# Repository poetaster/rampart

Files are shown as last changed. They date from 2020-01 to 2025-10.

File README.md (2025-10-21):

# rampart
An arduino semi-modular synth companion to keep, moat and bastl's kastle.

Rampart can use an Arduino Nano or an LGT8F238. I sell them with the latter chip since it's twice as fast and has on more 16 bit timer:

 The Mozzi library is used for some synthesis sketches and some are just direct PWM with timers.

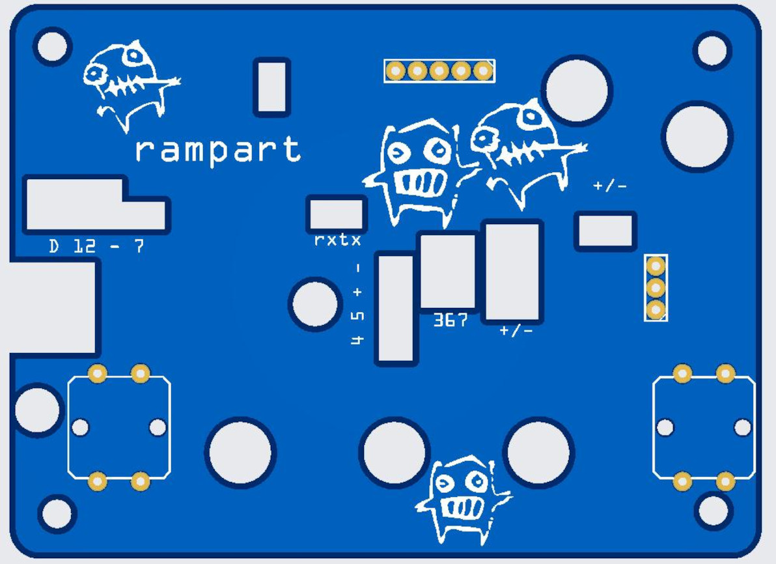
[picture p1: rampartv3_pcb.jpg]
V3 top pcb


## Hardware

* 3 pots
* 1 encoder w/button
* 2 buttons
* tactile switch w/LED
* CV inputs (analog)
* header for a SSD1306 display 
* analog filter/volume control
* audio/clock in
* audio wired stereo out
* headers for most digital and analog pins

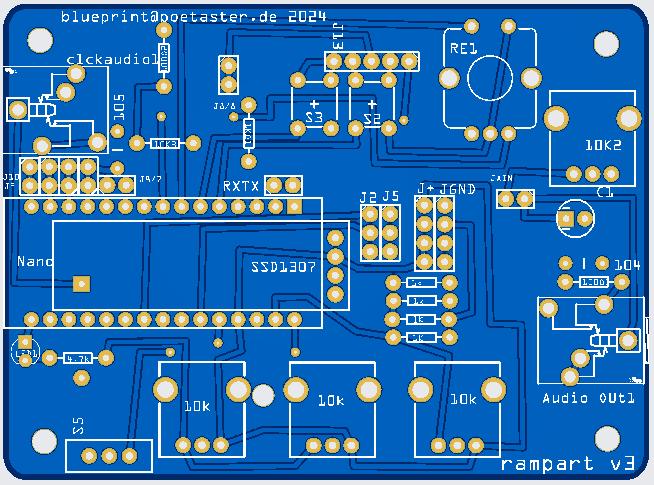
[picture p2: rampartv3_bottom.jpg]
V3 bottom pcb


Analog Pins 0-2 are potentionmeters. Analog pins 3-7 (4 avaible as an input) are used for modulation signal inputs. 

Pins 4&5, also SCL/SDA are layed out such that a SSD1306 could be used for a display.

Digital Pin 9 is audio (PWM) out, the Mozzi standard. 

Digital 2 - 6 are used for two buttons, an encoder and encoder button.

The layout includes an analog lowpass/volume knob and analog clock/audio in (pocket operator compatible).

The two buttons are located on the top pcb as is a 3pin header which is layed out GND/IO/VCC for connecting things like touch panels.

## Fritzing 

There are two Fritzing files used, one for the main pcb and one for the top (pictured above).

## Physical inputs

A note on -/+ located to the left below the volume knob ... these can also be used as input ;) If you take an internal signal (say my moat or a korg micromodular) you can use the filter to simply 'mix' the signals.

## Arduino Sketches

Of the sketches in the Firmware directory, those I use often and are well tested:
1. rampart3-bytebeats
2. DUAL_LFO
3. Modulove alternate function generator (burst, generative sequence, polyrythm, adsr, multimode env).
4. shepard-FM-chord 3 synths in one.

These can be flashed using the webflasher at https://poetater.org/webflasher 

To edit the sketches you can use the arduino ide. 
* install the ide from https://www.arduino.cc/en/software (I still use the 1.8.19 version)
* install the board support https://github.com/dbuezas/lgt8fx#how-to-install
* install the support library EncoderButton from Philip Fletcher (-> Tools -> Manage Libraries)
* download the lates source code from https://github.com/poetaster/rampart/releases (or do a git clone if you use git)
* open up a sketch in the firmware directory ( for instance rampart3-bytebeat)

The currently most complete sketch is the rampart3-bytebeat sketch. 

A number of Arduino sketches being updated include 2 synths (switch with button 3 on digital pin 2) which have 3 to 4 variable parts of the signal. Both sketches share the wavepacket object as 1st synth. One has PDResonant as second, one an FM synth as second synth.

So, Patch 1 is always a wavelet (based on the wavelet example with mozzi) synth and Patch 2 is an FM synth or PDResonant. Also still rough ideas.

This synth works well with Keep (moat), my analog synth and also with Bastl's Kastle synth. I've also played it with Korg's micro modular which works quiet well (in both directions).

I've included a granular synth without mozzi as an example and two versions of a 'glitch synth' from other sources modified to work with rampart.

## Upgrading firmware with hex files

First ensure you have drivers installed if you're on windows or mac. On linux you should not need to install a driver. A good reference for the usb drivers (which work form most arduino boards or the lgt in rampart):
https://learn.sparkfun.com/tutorials/how-to-install-ch340-drivers/all

The most current firmware hex files will be included in this directory and can be flashed  as follows

### linux: the device will most probably be ttyUSB0 as below:

* install avrdude using package manager 
* attach the rampart  to usb
* execute: avrdude -c arduino -b 57600 -F -P /dev/ttyUSB0 -p atmega328p -U flash:w:rampart3-bytebeats.ino.hex

### windows:

* having installed the driver, above
* install avrdude from https://github.com/avrdudes/avrdude/releases (windows x64, x86 or arm64)
* attach the rampart  to usb
* execute command: wmic path Win32_SerialPort Where "Caption LIKE '%%COM%%'" Get Description, DeviceID
* note the DeviceID of the "USB Serial Device" which will  be something like: "COM5" 
* using the DeviceID you've noted, adapt the following command (here -PCOM5).
* in the directory where you placed the hex file execute: avrdude.exe -patmega328p -carduino -D -PCOM5 -b57600 -Uflash:w:rampart3-bytebeats.ino.hex

### macintosh:

* install the usb driver for the rampart using instructions from : https://github.com/WCHSoftGroup/ch34xser_macos has a .pkg file you can install.
* install avrdude through MacPorts or Homebrew. (with home-brew it: brew install avrdude).
* attach the rampart  to usb
* in a terminal execute: "ls /dev/tty*" and note names with tty.wch in them  like : tty.wchusbserial1234
* from the directory where you downloaded the hex file execute: avrdude -c arduino -b 57600 -F -P /dev/tty.wchusbserial1234 -p atmega328p -U flash:w:rampart3-bytebeats.ino.hex

## Sales :)

I sell the latest versions of these as kits and completeed build at https://poetaster.org, on https://tonetoys.etsy.com and on Tindie:


# Historical versions

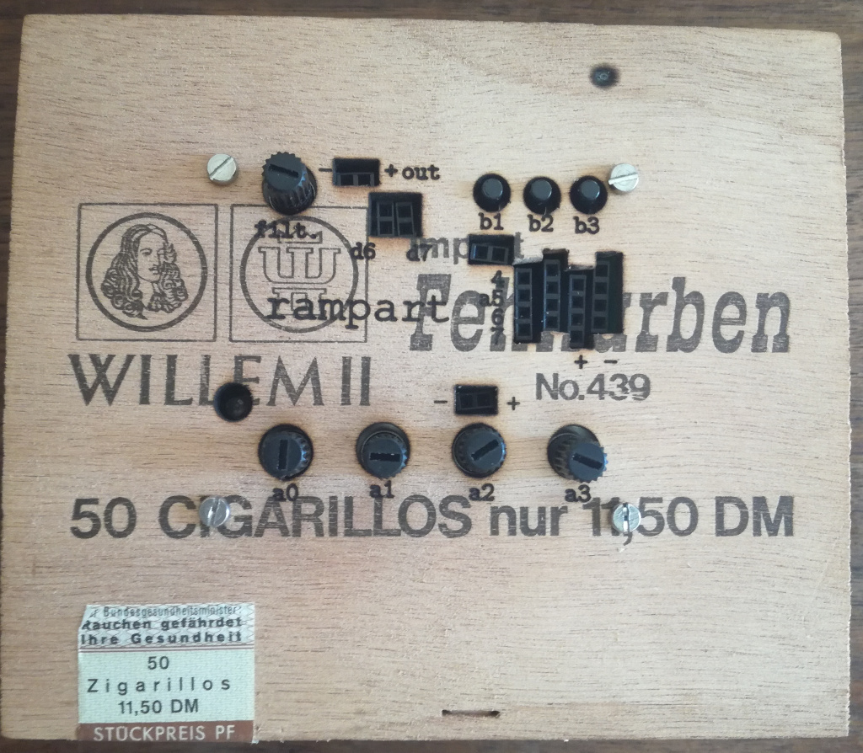
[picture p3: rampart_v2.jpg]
laser cut and etched prototype, v2


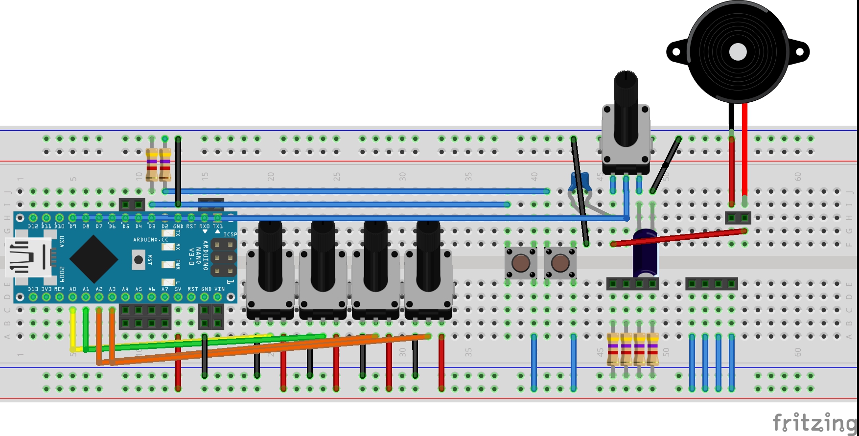
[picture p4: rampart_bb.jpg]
BreadBoard view


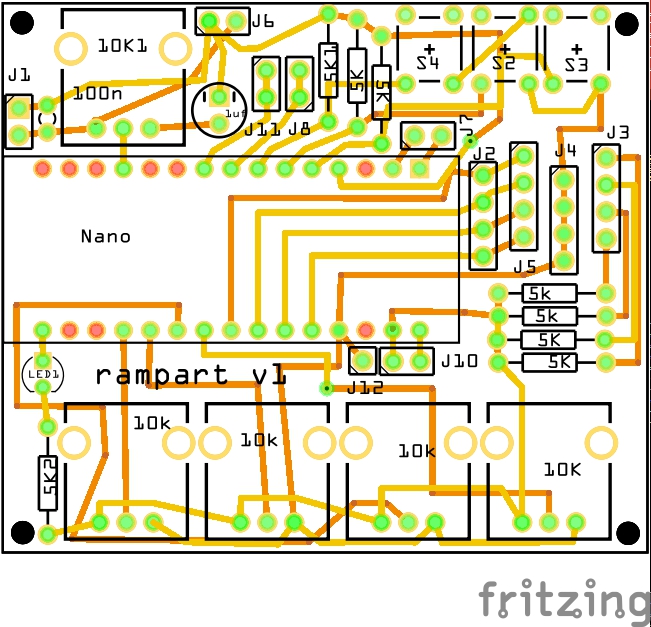
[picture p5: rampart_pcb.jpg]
PCB view


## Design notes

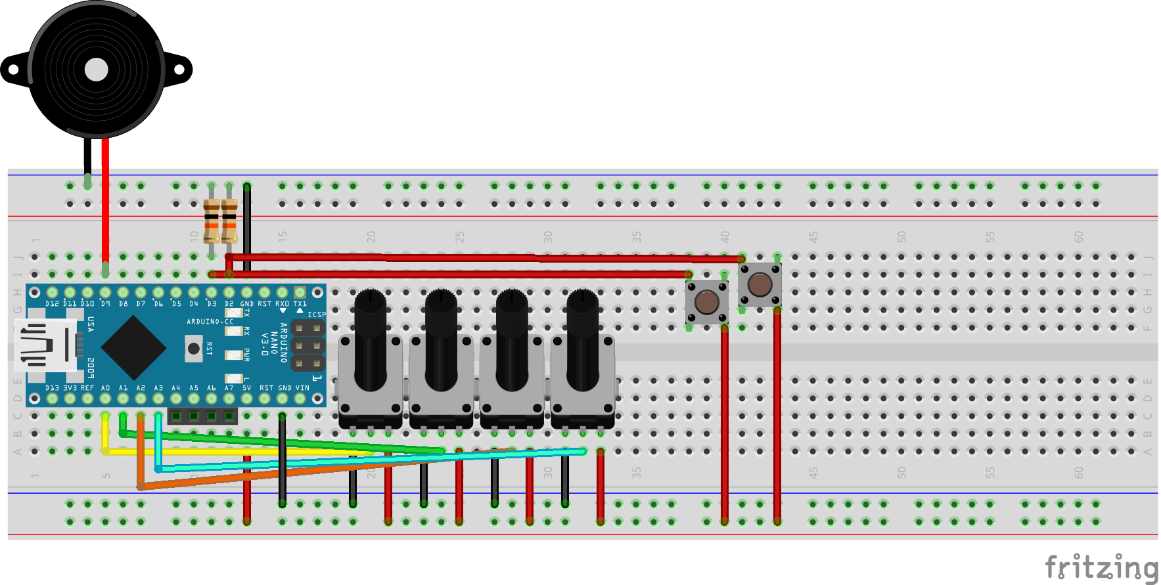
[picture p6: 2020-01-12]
rampart_bb.png

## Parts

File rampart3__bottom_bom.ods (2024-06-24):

Label | Part Type | mn | mpn | part number | cost | price
100Ω1 | 100Ω Resistor |  |  |  | 0.01 | 0.015
100Ω2 | 100Ω Resistor |  |  |  | 0.01 | 0.015
104 | Capacitor |  |  |  | 0.03 | 0.045
105 | Capacitor |  |  |  | 0.03 | 0.045
10k | Rotary Potentiometer (Small) |  |  |  | 0.17 | 0.255
10k | Rotary Potentiometer (Small) |  |  |  | 0.17 | 0.255
10k | Rotary Potentiometer (Small) |  |  |  | 0.17 | 0.255
10K2 | Rotary Potentiometer (Small) |  |  |  | 0.17 | 0.255
10K3 | 10kΩ Resistor |  |  |  | 0.01 | 0.015
1K | 1kΩ Resistor |  |  |  | 0.01 | 0.015
1K | 4.7kΩ Resistor |  |  |  | 0.01 | 0.015
1k | 1kΩ Resistor |  |  |  | 0.01 | 0.015
1k | 1kΩ Resistor |  |  |  | 0.01 | 0.015
1KΩ1 | 1kΩ Resistor |  |  |  | 0.01 | 0.015
4.7k | 4.7kΩ Resistor |  |  |  | 0.01 | 0.015
Audio OUt1 | Audio Jack (TRS) 3.5mm |  |  |  | 0.25 | 0.375
clckaudio1 | Audio Jack (TRS) 3.5mm |  |  |  | 0.25 | 0.375
J+ | Generic female header - 4 pins |  |  |  | 0.06 | 0.09
J2 | Generic female header - 3 pins |  |  |  | 0.05 | 0.075
J5 | Generic female header - 3 pins |  |  |  | 0.05 | 0.075
J9 | Generic female header - 2 pins |  |  |  | 0.04 | 0.06
J10 | Generic female header - 2 pins |  |  |  | 0.04 | 0.06
J11 | Generic female header - 2 pins |  |  |  | 0.04 | 0.06
J12 | Generic female header - 2 pins |  |  |  | 0.04 | 0.06
J13 | Generic female header - 5 pins |  |  |  | 0.06 | 0.09
J8/7 | Generic female header - 2 pins |  |  |  | 0.04 | 0.06
J8/8 | Generic female header - 2 pins |  |  |  | 0.04 | 0.06
JAIN | Generic female header - 2 pins |  |  |  | 0.04 | 0.06
JGND | Generic female header - 4 pins |  |  |  | 0.06 | 0.09
LED1 | Red (633nm) LED |  |  |  | 0.01 | 0.015
Nano | Arduino Nano (Rev3.0) |  |  |  | 1.9 | 2.85
RE1 | Rotary Encoder |  |  |  | 0.7 | 1.05
RXTX | Generic female header - 2 pins |  |  |  | 0.04 | 0.06
S2 | Pushbutton |  |  |  | 0.06 | 0.09
S3 | Pushbutton |  |  |  | 0.06 | 0.09
S5 | SPST Switch |  |  |  | 0.04 | 0.06
SSD1307 | OLED Mono 0.56 inch blue or white |  |  |  | 2.35 | 3.525 | 2.50 long | 4.04 large
VCC1 | 4 x AAA Battery Mount |  |  |  | 0.89 | 1.335
Jarduino | Generic female header - 15 low pins |  |  | 2x.26 | 0.5 | 0.75
Capacitive | Touch button |  |  |  | 0.3 | 0.45
Mounting | nuts&bolts |  |  |  | 0.48 | 0.72
Wires | breadboard jumper wire |  |  |  | 0.38 | 0.57
Nobs | Potentiometer Nnob |  |  | 5 | 0.28 | 0.42
PCB | top |  |  |  | 1.5 | 2.25
PCB | bottom |  |  |  | 1.5 | 2.25
 |  |  |  |  |  | 0 |  | kit | built
TOTAL |  |  |  |  | 12.88 | 19.32 |  | 42 | 78
Amount | Part Type | mn | mpn | part number
2 | 100Ω Resistor
1 | 10kΩ Resistor
4 | 1kΩ Resistor
1 | 4 x AAA Battery Mount
2 | 4.7kΩ Resistor
1 | Arduino Nano (Rev3.0)
2 | Audio Jack (TRS) 3.5mm
2 | Capacitor
8 | Generic female header - 2 pins
2 | Generic female header - 3 pins
2 | Generic female header - 4 pins
1 | Generic female header - 5 pins
1 | OLED Mono 0.56 inch blue or white
2 | Pushbutton
1 | Red (633nm) LED
1 | Rotary Encoder
4 | Rotary Potentiometer (Small)
1 | SPST Switch
2 | PCB

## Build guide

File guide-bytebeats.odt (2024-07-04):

# Rampart, bytebeats guide

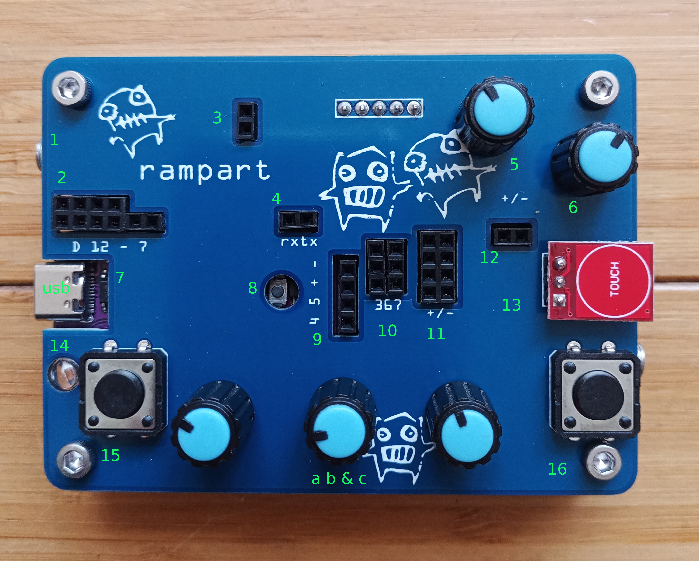
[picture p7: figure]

## Connections overview

Since rampart is more platform than any given instrument, this overview tries to cover ground that isnt’ just relevant to the bytebeats sketch.

1. - audio (right channel) & clock (left) input. Pocket-operator can be directly connected .Clock comes out at 4 (tx) and can be plugged into 10 (inputs 3, 6 or 7).

2. digital input/outputs. For bytebeats, 11 needs to be wired to 9 (second from left to 4th from left)

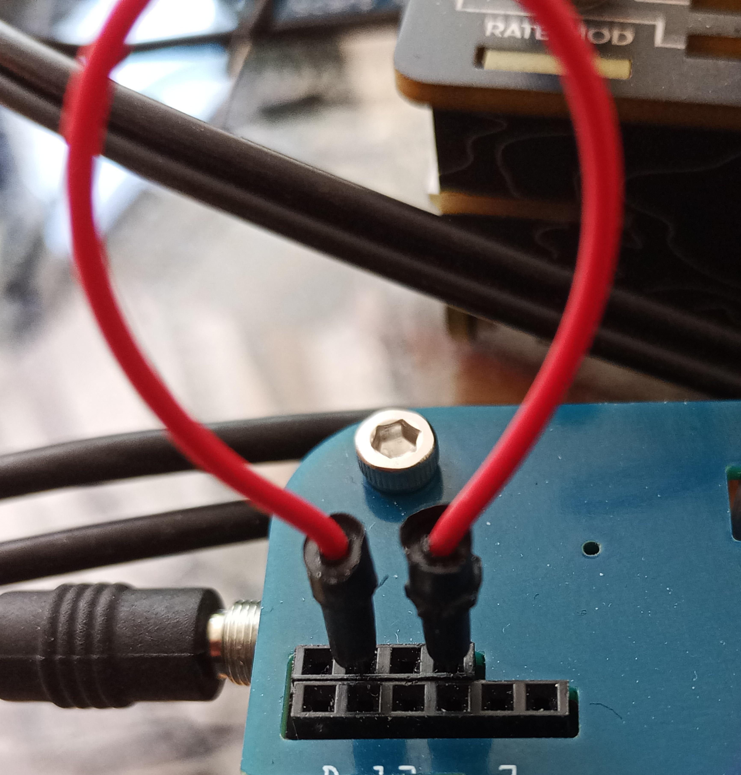
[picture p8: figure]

3. touch output (from 13). Can be used on the digital pins, (11!) or 3,6 or 7 (at 10).

4. two pins rx and tx (receive and transmit) The clock signal from 1 goes to tx on the right pin at 4. Bytebeats connect to 3,6 or 7 to modulate a b & c (in addition to the pots a b & c)

5. encoder / button: a) turning will increase or decrease the frequency, starting on boot at 8000 HZ, steps of 64 HZ. b) Push and hold down and turn left, play backwards at increasing frequency; turn right and forwards increasing frequency (doubling). c) single click: bank 1 of formulas, double click: bank 2, triple click :bank 3

6. volume/filter it’s advisable to start bytebeats with this at 12 o’clock to avoid harsher high end. Will also mix the relative loudness of input from 1 vs. the ramparts internal audio.

7. usb power/programming and 8 reset button, if rampart should hang which happens rarely, but can at higher frequencies

9. Two analog inputs (4&5) and + /- power. Not directly used in the bytebeats sketch

10. analog inputs 3, 6 and 7 (rows 2x3, 2x6, 2x7) used to modify bytebeats params a/b/c in addition to the pots labeled a b & c at the bottom.

11. +/- power columns which aren’t used for the bytebeats sketch, but one can, for instance put a capacitor from + to inputs at 10 to create a contral voltage. Very fun with a 1uf Elko.

12. +/ - sides of the audio output. You can plug in additional signals or tap the output

13. Touch button with LED, see 3

15/16. Left & Right buttons select previous and next program of bank

Bottom right, barely visible is the audio out. You can plug-in headphones, but turn down 6, vol. First. If you plug in stereo audio to the input, it will feed through but moving the encoder or pushing buttons will make noises. A PO or Scarp signal will be clean (split clock).

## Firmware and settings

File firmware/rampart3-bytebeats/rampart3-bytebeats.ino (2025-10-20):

/*
   Rampart Bytebeats @copyright 2024, Mark Washeim <blueprint@poetaster.de>
   GPLv3, see LICENSE
   some parts use other licensces (nyblybyte.h is MIT)
   and some parts are Public Domain in as far as permissible by law

   a number of formulas https://raw.githubusercontent.com/schollz/nyblcore/main/bytebeat/bytebeat.ino

   Many contributions from the internet :) See nyblybyte.h for many equations origins and original form.
*/




#include <EncoderButton.h>


// for pwm init functions
const unsigned int TOP = 0x07FF; // 11-bit resolution.  7812 Hz PWM

// noise reduction for cv reads
uint16_t potvalue[3]; // pot readings
uint16_t lastpotvalue[3]; // old pot readings
#define POT_SAMPLE_TIME 30 // delay time between pot reads
#define MIN_POT_CHANGE 25 // locked pot reading must change by this in order to register
#define MIN_COUNTS 20  // unlocked pot must change by this in order to register
#define POT_AVERAGING 3 // analog sample averaging count 
#define POT_MIN 4   // A/D may not read min value of 0 so use a bit larger value for map() function
#define POT_MAX 1019 // A/D may not read max value of 1023 so use a bit smaller value for map() function

#define LEDPIN   13 // usually 13
#define PWMPIN 11


// for the sine waves
unsigned int Acc[3];
unsigned long freq[3];
unsigned int tune, pitch;
byte pot[] = {A1, A2, A3};
// from levitation osc.


long t = 0;
volatile int a, b, c, i;
volatile int offA, offB, offC;
volatile int result;
int d = 0; // hmm?

int prog = 1;
int bank = 1;
int banktotal = 3;
int pb1 = 1;
int pb1total = 25;
int pb2 = 1;
int pb2total = 29;
int pb3 = 1;
int pb3total = 20;

int numProg = 73;

// these ranges are provisional and in schollz equations need to be reset
volatile int aMax = 99, aMin = 0, bMax = 99, bMin = 0, cMax = 99, cMin = 0;

// default rate close to the original bytebeat speed
int SRATE = 8192; // 16384;

bool debug = false;

// encoder
// the a and b + the button pin large encoders are 6,5,4
EncoderButton eb1(5, 6, 4);

// the library has nice button handling and uses bounce2
EncoderButton left(3); // pin 3 rampart
EncoderButton right(2); // pin 2 rampart

int encoder_pos_last = 0;
long encoder_delta = 0;
int enc_offset = 1; // changes direction
int enc_delta; // which direction


#include "bytebeats.h" // forwards

// some constants for sound production these are the old ones.
//counter for sound
float floatI = 0;
float tempo = 16;
int currentSound = 4;
int iterations = 256;

// analog freq pins OLD
#define TEMPO 0
#define ITERATIONS 1

long timeoffset = 0;

/**
   handle encoder button long press event
*/
void onEb1LongPress(EncoderButton& eb) {
  
  if (debug) {
    Serial.print("button1 longPressCount: ");
    Serial.println(eb.longPressCount());
  }
}
/**
   handle encoder turn with  button pressed
   offsets OCR2A
*/
void onEb1PressTurn(EncoderButton& eb) {
  enc_delta = eb.increment();

  int dir = enc_offset + eb.increment();
  dir = constrain(dir, -7, 7 );

  enc_offset = dir;
  if (debug) {
    Serial.print("eb1 press inc by: ");
    Serial.println(eb.increment());
    Serial.print("enc_offset is: ");
    Serial.println(enc_offset);
  }
}

/**
   handle encoder turn with  button pressed
*/
void onEb1Clicked(EncoderButton& eb) {

  // set which bank to select formulas from
  bank = eb.clickCount();

  if (debug) {
    Serial.print("bank: ");
    Serial.println(eb.clickCount());
  }
  // displayUpdate();
}

/**
    handle left button short release
*/
void onLeftReleased(EncoderButton& left) {

  if (bank == 1)
  {
    if (pb1 > 1) {
      pb1--;
    } else if (pb1 == 1) {
      pb1 = pb1total;
    }
    prog = pb1;
  } 
  else if (bank == 2) {
    if (pb2 > 1) {
      pb2--;
    } else if (pb2 == 1) {
      pb2 = pb2total;
    }
    prog = pb2;
  } 
  else if (bank == 3) {
    if (pb3 > 1) {
      pb3--;
    } else if (pb3 == 1) {
      pb3 = pb3total;
    }
    prog = pb3;
  }

  if (debug) {
    Serial.print("PROGRAM: ");
    Serial.println(prog);
  }
}

/**
    handle right button short release
*/
void onRightReleased(EncoderButton& right) {
  
  if (bank == 1)
  {
    if (pb1 < pb1total) {
      pb1++;
    } else if (pb1 == pb1total) {
      pb1 = 1;
    }
    prog = pb1;
  } 
  else if (bank == 2) {
    if (pb2 < pb2total) {
      pb2++;
    } else if (pb2 == pb2total) {
      pb2 = 1;
    }
    prog = pb2;
  } 
  else if (bank == 3) {
    if (pb3 < pb3total) {
      pb3++;
    } else if (pb3 == pb3total) {
      pb3 = 1;
    }
    prog = pb3;
  }

  if (debug) {
    Serial.print("PROGRAM: ");
    Serial.println(prog);
  }
}

/**
   A function to handle the 'encoder' event without button
*/
void onEb1Encoder(EncoderButton& eb) {

  //displayUpdate();
  encoder_delta = eb.increment();
  long cstep = eb.increment() * 64;
  long oSRATE = SRATE;
  SRATE = SRATE + cstep;

  if (SRATE != oSRATE) {
    OCR1A = F_CPU / SRATE;
  }

  if (debug) {
    Serial.print("eb1 incremented by: ");
    Serial.println(eb.increment());
    Serial.print("eb1 position is: ");
    Serial.println(SRATE);
  }
}

// values to compare input on CV pins
int lastA = 0;
int lastB = 0;
int lastC = 0;

void setup() {

  if (debug) {
    Serial.begin(57600);
    Serial.println(F("Started"));
  }


  
  pinMode(LEDPIN, OUTPUT);
  pinMode(PWMPIN, OUTPUT);
  
  //lastA =  analogRead(A3);
  //lastB =  analogRead(A6);
  //lastC =  analogRead(A7);
  
  pwmSetup();

  //Link the event(s) to your function
  eb1.setClickHandler(onEb1Clicked);
  eb1.setEncoderHandler(onEb1Encoder);
  eb1.setLongPressHandler(onEb1LongPress, true);
  eb1.setEncoderPressedHandler(onEb1PressTurn);

  // program up/down buttons
  left.setReleasedHandler(onLeftReleased);
  left.setRateLimit(7);
  right.setReleasedHandler(onRightReleased);
  right.setRateLimit(6);

}


void updateControl() {

  // this was old code from the midi-boy bytebeats sketch
  // tempo = map( analogRead(TEMPO), 0, 1023, 1, 256);
  // iterations = map( analogRead(ITERATIONS), 0, 1023, 16, 256);
  
  // EncoderButton object updates
  eb1.update();
  left.update();
  right.update();
  
  if (millis() > timeoffset + 50 ) {
    timeoffset = millis();
    //display_value(SRATE);
    if (result > 5000) digitalWrite(LEDPIN, HIGH);
    if (result < 1000) digitalWrite(LEDPIN, LOW);

  }
  // for the wave synth


  //if ( debug ) Serial.println(freq[0]);
  //if ( debug ) Serial.println(pgm_read_byte(&sine256[Acc[0] >> 8]) + pgm_read_byte(&sine256[Acc[1] >> 8]) + pgm_read_byte(&sine256[Acc[2] >> 8]));//Acc[0]>>8);




}

void loop() {
  updateControl(); // required here
  adc();
  knobs();

  
}



// used for mapping adc input on pins 5 - 7 to a - c
void adc() {
  // this is just very wrong ;)
  // take the average on the input on pin 3,6,7
  uint16_t A =  map(readcv(0), 0, 1023, aMin, aMax);
  uint16_t B =  map(readcv(1), 0, 1023, aMin, aMax);
  uint16_t C =  map(readcv(2), 0, 1023, aMin, aMax);
  
    if (abs(lastA - A) > 1) {
      lastA = A;
      offA = lastA / 2;
      if (debug) Serial.println(A);

    }

    if (abs(lastB - B) > 1) {
      lastB = B;
      offB = lastB / 2;

    }

    if (abs(lastC - C) > 1) {
      lastC = C;
      offC = lastC / 2 ;

    }

}

uint16_t readcv(uint8_t potnum) {
  int val = 0;
  int input;
  switch (potnum) { // map potnum to pin
    case 0:
      input = A3;
      break;
    case 1:
      input = A6;
      break;
    case 2:
      input = A7;
      break;
  }
  // note that Pikocore pots are wired "backwards" - max voltage is full ccw
  for (int j = 0; j < POT_AVERAGING; ++j) val += (analogRead(input)); // read the A/D a few times and average for a more stable value
  val = val / POT_AVERAGING;
 
  if (abs(lastpotvalue[potnum] - val) > MIN_COUNTS ) { 
    lastpotvalue[potnum] = val; // even if pot is unlocked, make sure pot has moved at least MIN_COUNT counts so values don't jump around
  }  else {
    val = lastpotvalue[potnum];
  }
    
 potvalue[potnum] = val; // pot is unlocked so save the reading

  return val;
}

// pot inputs
void knobs() {
  a = map(analogRead(A0), 0, 1023, aMin, aMax) + offA;
  b = map(analogRead(A1), 0, 1023, bMin, bMax) + offB;
  c = map(analogRead(A2), 0, 1023, cMin, cMax) + offC;
}


// show a number in binary on the LEDs
void display_value(int16_t value) {
  for (int i = 7; i >= 0; i--) { // NOPE + 1 can loop this way because port assignments are sequential
    //digitalWrite(led[i], result & 1);
    value = value >> 1;
  }
  //display_timer = millis();
}

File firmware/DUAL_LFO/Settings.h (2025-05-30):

// Settings 

// Comment out the following #define to deactivate SYNC input(s)
// Specify whether HIGH or LOW is the trigger state using "TRIGGER" constants
// To use a common pin for syncing both LFOs, define SYNC_COMMON (uncomment the #define)
// The common pin/trigger are taken from SYNC1

#define SYNC
#if defined(SYNC)
#define SYNC_COMMON
const byte SYNC1_PIN =            11;
const byte SYNC1_TRIGGER =        HIGH;
const byte SYNC2_PIN =            12;
const byte SYNC2_TRIGGER =        HIGH;
#endif

// Uncomment this to initialize and update a user-supplied display
//#define DISPLAY

// KNOBS (analog pins)

const byte FREQ1_KNOB_PIN =         0;
const byte DEPTH1_KNOB_PIN =        1;

const byte FREQ2_KNOB_PIN =         2;
const byte DEPTH2_KNOB_PIN =        3;

// SWITCHES (digital pins)

const byte WAVE1_SWITCH_PIN =      3;
const byte WAVE2_SWITCH_PIN =      2;

// LFO SETTINGS
const double LFO1_FREQ_MIN =      0.1;
const double LFO1_FREQ_MAX =      50;

const double LFO2_FREQ_MIN =      0.1;
const double LFO2_FREQ_MAX =      50;

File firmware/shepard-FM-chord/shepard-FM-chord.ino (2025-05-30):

/*   This program is based on the Mozzi examples WavePacket_Double and FMsynth
     Mark Washeim <blueprint@poetaster.de) 2020, public domain.

     Tim Barrass 2013, CC by-nc-sa.
*/

//#include <ADC.h>  // Teensy 3.0/3.1 uncomment this line and install http://github.com/pedvide/ADC
#include <MozziConfigValues.h>
#include <Mozzi.h>
#include <mozzi_analog.h>
// for FMsynth
#include <Oscil.h>
#include <tables/cos2048_int8.h> // table for Oscils to play
#include <tables/triangle2048_int8.h> // for chord synth
#include <mozzi_midi.h>
#include <mozzi_rand.h>
#include <mozzi_fixmath.h>
#include <Smooth.h>
#include <EventDelay.h>
#include <Line.h>
#include <ADSR.h>
#include <Midier.h>

#define MOZZI_AUDIO_RATE 32768
#define MOZZI_CONTROL_RATE 256
//#define MOZZI_PWM_RATE 32768
// Envelopes
// --------------------------------------------------------------------
ADSR <MOZZI_AUDIO_RATE, MOZZI_AUDIO_RATE, unsigned long> envelopeVCO;

bool debug = false;

// analog freq pins
#define FUNDAMENTAL_PIN A0
#define BANDWIDTH_PIN A1
#define CENTREFREQ_PIN A2

// modulation pins analog
#define VOCT A3
#define P1CV A6
#define P2CV A7
#define FLT_PIN 5
#define SW_PIN_1 4
#define SW_PIN_2 5

#define GAIN_CV_PIN A4
#define MODE_CV_PIN A5
// Map Analogue channels

//shepard tone
#include <tables/sin8192_int8.h>
// reset and sync vol and freq controls each cycle
EventDelay  kTriggerDelay0;
EventDelay  kTriggerDelay1;
EventDelay  kTriggerDelay2;
const UFix<7, 0> NOTE_CENTRE = 60, NOTE_RANGE = 12;
const UFix<7, 0> NOTE_START_FIXEDPOINT = NOTE_CENTRE + NOTE_RANGE;
const UFix<7, 0> NOTE_END_FIXEDPOINT = NOTE_CENTRE - NOTE_RANGE;
#define GLISS_SECONDS 1.f
float glisssecs = 1.f;
//#define CONTROL_STEPS_PER_GLISS ((unsigned int)((float)MOZZI_CONTROL_RATE * GLISS_SECONDS))
#define CONTROL_STEPS_PER_GLISS ((unsigned int)((float)MOZZI_CONTROL_RATE * GLISS_SECONDS))
Line <UFix<7, 9>> kGliss0; // Line to slide frequency
Line <UFix<7, 9>> kGliss1; // Line to slide frequency
Line <UFix<7, 9>> kGliss2; // Line to slide frequency
// audio volumes updated each control interrupt and reused in audio
SFix<0, 14> v0, v1;
// harmonics using the other osc

// harmonics
Oscil<SIN8192_NUM_CELLS, MOZZI_AUDIO_RATE> aShep0(SIN8192_DATA);
Oscil<SIN8192_NUM_CELLS, MOZZI_AUDIO_RATE> aShep1(SIN8192_DATA);
Oscil<SIN8192_NUM_CELLS, MOZZI_AUDIO_RATE> aShep2(SIN8192_DATA);


// chordsynth

const midier::Note notes[] = {
  midier::Note::C,
  midier::Note::C,
  midier::Note::D,
  midier::Note::D,
  midier::Note::E,
  midier::Note::F,
  midier::Note::F,
  midier::Note::G,
  midier::Note::G,
  midier::Note::A,
  midier::Note::A,
  midier::Note::B,

};
const midier::Quality qualities[] = {
  midier::Quality::major,
  midier::Quality::aug,
  midier::Quality::minor,
  midier::Quality::dim,
  midier::Quality::m7b5,
  midier::Quality::m7,
  midier::Quality::dom7,
  midier::Quality::maj7,
  midier::Quality::aug7,
};
const midier::Degree degrees[] = { 1, 3, 5, 7 };
midier::Quality quality = midier::Quality::major; // boring :)

// harmonics
Oscil<TRIANGLE2048_NUM_CELLS, MOZZI_AUDIO_RATE> aCos1(TRIANGLE2048_DATA);
Oscil<TRIANGLE2048_NUM_CELLS, MOZZI_AUDIO_RATE> aCos2(TRIANGLE2048_DATA);
Oscil<TRIANGLE2048_NUM_CELLS, MOZZI_AUDIO_RATE> aCos3(TRIANGLE2048_DATA);
Oscil<TRIANGLE2048_NUM_CELLS, MOZZI_AUDIO_RATE> aCos4(TRIANGLE2048_DATA);
// duplicates but slightly off frequency for adding to originals
Oscil<TRIANGLE2048_NUM_CELLS, MOZZI_AUDIO_RATE> aCos1b(TRIANGLE2048_DATA);
Oscil<TRIANGLE2048_NUM_CELLS, MOZZI_AUDIO_RATE> aCos2b(TRIANGLE2048_DATA);
Oscil<TRIANGLE2048_NUM_CELLS, MOZZI_AUDIO_RATE> aCos3b(TRIANGLE2048_DATA);
Oscil<TRIANGLE2048_NUM_CELLS, MOZZI_AUDIO_RATE> aCos4b(TRIANGLE2048_DATA);


// base pitch frequencies in Q16n16 fixed int format (for speed later)
int f1, f2, f3, f4, f5, f6, f7;

// for FMsynth

Oscil<COS2048_NUM_CELLS, MOZZI_AUDIO_RATE> aCarrier(COS2048_DATA);
Oscil<COS2048_NUM_CELLS, MOZZI_AUDIO_RATE> aModulator(COS2048_DATA);
Oscil<COS2048_NUM_CELLS, MOZZI_AUDIO_RATE> aModDepth(COS2048_DATA);
Oscil<COS2048_NUM_CELLS, MOZZI_CONTROL_RATE> kModIndex(COS2048_DATA);
Q8n8 mod_index;// = float_to_Q8n8(2.0f); // constant version
Q16n16 deviation;
Q16n16 carrier_freq, mod_freq, fundemental, bandwidth, centre;

// FM ratio between oscillator frequencies, stays the same through note range
Q8n8 mod_to_carrier_ratio = float_to_Q8n8(3.f);

long fmIntensity; // Carries control info from updateControl to updateAudio
// smoothing for intensity to remove clicks on transitions
float smoothness = 0.95f;
Smooth <long> aSmoothIntensity(smoothness);


int gain;

// for note changes not really using this
Q7n8 last_note, note_upper_limit, note_lower_limit, note_change_step, smoothed_note;


int gain_val = 0;
uint8_t mode = 0;
uint16_t mode_val = 0;
unsigned int notesPlaying;
bool notePlaying = false;
bool noteReset = true;

#include "encoder.h"

void setup() {
  if (debug) {
    Serial.begin(57600);
    Serial.println("hi there");
  }
  //Link the encoder event(s) functions in encoder.h
  eb1.setClickHandler(onEb1Clicked);
  eb1.setEncoderHandler(onEb1Encoder);
  eb1.setLongPressHandler(onEb1LongPress, true);
  eb1.setEncoderPressedHandler(onEb1PressTurn);

  // program up/down buttons
  left.setReleasedHandler(onLeftReleased);
  //left.setRateLimit(7);
  right.setReleasedHandler(onRightReleased);
  //right.setRateLimit(6);
  // initialize the pushbutton pin as an input:
  



  // wavepacket sample
  //   wavey.setTable(RAVEN_ARH_DATA);
  // chordsynth
  // select base frequencies using mtof (midi to freq) and fixed-point numbers
  f1 = mtof(48);
  f2 = mtof(74);
  f3 = mtof(64);
  f4 = mtof(77);
  // set Oscils with chosen frequencies
  aCos1.setFreq(f1);
  aCos2.setFreq(f2);
  aCos3.setFreq(f3);
  aCos4.setFreq(f4);
  // set frequencies of duplicate oscillators
  aCos1b.setFreq(f1 + 3);
  aCos2b.setFreq(f2 + 1);
  aCos3b.setFreq(f3 + 5);
  aCos4b.setFreq(f4 + 2);

  // filter setup
  //svf.setResonance(48); // 0 to 255, 0 is the "sharp" end
  //svf.setCentreFreq(1000);

  // FMsetup

  kModIndex.setFreq(.768f); // sync with kNoteChangeDelay

  // might add back

  envelopeVCO.setADLevels(25, 25);
  envelopeVCO.setTimes(10, 100, 6000, 2000); // 10000 is so the note will sustain 10 seconds unless a noteOff comes

  // for the env
  randSeed(); // fresh random

  // shepard
  kTriggerDelay0.start(0); // start trigger before polling in updateControl()
  kTriggerDelay1.start((int)((GLISS_SECONDS * 50.f) / 2.f));
  kTriggerDelay2.start((int)((GLISS_SECONDS * 100.f) / 2.f));

  startMozzi(CONTROL_RATE);
}
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

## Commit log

2020-01-12 initial addtion of fritzing design
    [rampart.fzz]
2020-01-12 Basic layout, BB and PCB
2020-01-12 This is a version passing design rules.
    [rampart.fzz]
2020-01-12 Cleanup button layout
    [rampart.fzz]
2020-01-13 Cleanup and correct part type, buttons.
    [rampart.fzz]
2020-01-14 Small corrections
    [rampart.fzz]
2020-01-28 Slight mods to code, rewriting. The wiring needs additional headers to + rail and resistors
2020-01-28 Added some digital ins, a simple filter, further inputs for anaolg 4-7, clean up.
    [rampart.fzz]
2020-01-28 Minor cleanup.
    [rampart.fzz]
2020-01-30 Replaced two smd parts and converted text from copper to screen
    [rampart.fzz]
2020-02-01 Added holes after correcting parts.
    [rampart.fzz]
2020-02-08 Modified the new PDreso based osc to better use input variation. Both time and frequency domain.
    [rampart.fzz]
2020-04-24 simple fixes to layout and small modification to arduino example to make the phasor be more 'playable'.
    [rampart.fzz]
2020-05-16 Added CAD files for cutting the top of a case.
2020-05-25 Corrected button handling.
2020-05-25 Added a button and an led on 13. 4 Digital i/0 and one (4) analog are 'free'.
    [rampart.fzz]
2020-05-25 Added 2 more digital i/0 pins.
    [rampart.fzz]
2020-05-25 small adjustment, spacing.
    [rampart.fzz]
2020-05-30 Minor alignement. This should get a version bump.
    [rampart.fzz]
2020-06-14 minor correction to mod index for the fm synth
    [WavePacket_FM-nano.ino]
2020-06-15 Corrected a trace on the PCB. Modified the io to the envelope and the type of envelope on the FM synth. It's at once simpler to play and easier to do percussive stuff with.
    [rampart.fzz]
2020-06-15 Added the main svg for the face plate. With text
2020-06-15 added recent image in laser etched box
2020-06-21 added proper 5 volt input. moved some resistors since one overlaps with pot.
    [rampart.fzz]
2020-06-24 made A4 more useful for random glitch trigger and added A7 to modulate bandwidth
    [rampartGlitchSynth.ino]
2020-07-05 added the button handling rework from GlitchArp to synth
    [rampartGlitchSynth.ino]
2020-11-24 Minor glitch arp mods and correct, new pcb image.
    [rampartGlitchArp.ino, rampartGlitchSynth.ino]
2020-12-04 Added the most recently used gcode files for laser cutting. The type burning needs to be improved, but it's usable.
    Also added some mods to example synths.
    [Detuned_Beats_Wash.ino, FMsynth-env.ino, PWM_Phasing.ino]
2020-12-04 Updated a couple of things and added two notes.
2020-12-04 Minor update on pin use.
2020-12-04 Corrected pin reference. These are confusing. Clean it up.
2020-12-22 Added a new layout where d pins 0 and 1 instead of 2 and 3 are used. this is to permit use of attachInterupt. NOT tested and the Arduino sketches are still using d pins 2 and 3.
    [rampart2.fzz]
2023-05-15 Add: Wavefolder test and relay_drum
2023-05-15 Fix: get it back to playing which involves commenting out line 22 of ~/Arduino/libraries/ArduinoSTL/src/new_handler.cpp
    [simple_samples.ino]
2024-03-25 Add: new variants
    [rampart2.fzz, rampart3.fzz, rampart_externaldac.fzz]
2024-03-27 Add: bytebeats example (timers) and update design
    [rampart3.fzz, rampart_externaldac.fzz]
2024-03-28 Mods: adding a switch, and some input headers, positioning. bytes.
    [rampart3.fzz]
2024-03-29 Fix: fix 19/20 algos
    [bytebeats.h, rampart3-bytebeats.ino]
2024-03-29 Fix: no. 9 got upgraded
    [bytebeats.h, rampart3-bytebeats.ino]
2024-03-30 Add: final headers, further bytebeat examples
    [rampart3.fzz]
2024-03-31 Add: , spacing for battery
    [rampart3.fzz]
2024-04-05 Add: some new formulas bytebeat and minor mods on the board
    [rampart3.fzz]
2024-04-10 Add: top pcb, minor
    [rampart3.fzz, rampart3_top.fzz]
2024-04-10 Add: art for the top cut
2024-04-16 Add: additional bytbeats, minor changes for testing and small hardware adjusts
    [rampart3.fzz, rampart3_top.fzz]
2024-04-22 Fixes: both hardware and software. impl. encoder button, remove all code from glitch storm since no lic.
    [rampart3.fzz, rampart3_top.fzz]
2024-04-22 Refactor: move button handling to encoder since it does all long/short events + debounce
    [bytebeats.h, rampart3-bytebeats.ino]
2024-04-22 Fix: remove some crashing formulas
    [bytebeats.h]
2024-04-24 [Release] the fzz and svgs off to manu. getting some more funk it (45-48)
    [rampart3.fzz, rampart3_top.fzz]
2024-05-02 Remove: old cad files, adding archival tar.
2024-05-02 Add: add the production ready gerbers
    [rampart3_filled_contour.gm1, rampart3_filled_copperBottom.gbl, rampart3_filled_copperTop.gtl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]
2024-05-02 Readme, bottom pcb picture
2024-05-02 Fixes: parameters needed to be moved around for modified inputs
    [FMsynth-env.ino, WavePacket_FM-nano.ino, WavePacket_PDreso-nano.ino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]
2024-05-04 Add: deps encoder and button
    [rampart3_bom_csv.csv]
2024-05-06 Fixes: start cleanup of schematic view
    [rampart3.fzz]
2024-06-24 Add: bom files
    [rampart3__bottom_bom.csv, rampart3__bottom_bom.ods]
2024-07-02 Fix: the adc values where killing the formulas
    [bytebeats.h, rampart3-bytebeats.ino]
2024-07-03 bytebeat fixes and firmware files
    [bytebeats.h, rampart3-bytebeats.ino]
2024-07-04 Fixes: corrected cv reading so that an offset is used and both touch and input cv work in parallel.
    [bytebeats.h, rampart3-bytebeats.ino]
2024-07-04 Fix, minor but useful code beauty.
    [rampart3-bytebeats.ino]
2024-07-17 Fixes: correcting the adc methods and adding a 3rd method to get wavepacket, fm and pdresno in one patch.
    [WavePacket_FM-nano.ino, WavePacket_PDreso-nano.ino, encoder.h]
2024-07-17 Fixes: primarily wavepacket and small adjusts.
    [WavePacket_FM-nano.ino]
2024-07-22 Fixes: for LFO output and input value acquisition
    [WavePacket_FM-nano.ino, encoder.h]
2024-08-21 Add: encoder header. some docs.
2024-09-04 Fix: make the cv input avging more precise
    [rampart3-bytebeats.ino]
2025-02-13 Fixes: various prog fixes, adding some offsets for appropriate speed
    [bytebeats.h, rampart3-bytebeats.ino]
2025-02-14 Fixes: additional beats, order and bank assignment
    [bytebeats.h, rampart3-bytebeats.ino]
2025-05-13 Fix: various fixes
    [rampart3.fzz]
2025-05-30 Add: correct addition of the 3 voice synth and add the dual lfo sketch
    [DUAL_LFO.ino, Settings.h]
2025-05-30 Add note about currently supported firmwares
2025-10-21 Fix: move functions from buttons to encoder
2026-04-13 [Update] move to long hold for program switch. make generative melody first program
2026-08-30 Add new layout using pico2zero and ads1115
    [rampart_pico.fzz]
2026-11-09 [Add] initial pico rampart sketch with Braids
2026-11-10 [Fix] adc imp 1
